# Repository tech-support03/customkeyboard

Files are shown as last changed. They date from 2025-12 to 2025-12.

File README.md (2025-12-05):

# customkeyboard

## A custom hotswapable keyboard with a 60% plus arrow keys layout

The purpose of this project was to learn about designing pcbs and how to make my own keyboard. I wanted to make something that was not a completely unique design but I wanted my own personal touch. It had to be small and portable, so I went with a 60% layout at first. However I really wanted arrow keys because they are very important to me in a keyboard layout, so I added them and it acutally led to better packaging overall. Another very important thing to me was hotswapability. I wanted the ability to change my switches if I wanted to. This led to its own set of challenges, but eventually it worked out pretty nicely. Additionally, I wanted a rotary encoder, so I put one in the top left corner. Finally, I wanted the microcontroller to be exposed because I think it looks pretty cool, so I made a cutout for it in the top right. Overall, this project was really fun to design!

### CAD
Full CAD




Top Plate


Base


PCB (Hotswap sockets!)


### PCB

Layout


Schematic


### BOM

| Item | Description | Link | Price | Quantity | Total |
|---|---|---|---|---|---|
| PCB | circuit board for all the components | https://jlcpcb.com | 20.70 | 1 | 22.64 |
| Raspberry Pi Pico | Microcontroller for keyboard | https://www.microcenter.com/product/661033/raspberry-pi-pico-microcontroller-development-board | 2.99  | 1 | 3.27 |
| Akko Cream Blue Switches | Tactile switches for keyboard, sold in packs of 45 | https://www.amazon.com/Akko-Cream-Blue-Tactile-Switches/dp/B0CL4FRWY8 | 25.98 | 1 | 28.41 |
| Womier Black keycaps | Keycaps for keyboard | https://www.amazon.com/Womier-Black-Pudding-Keycaps/dp/B0BN5F3B9S | 17.99 | 1 | 19.67 |
| Plate mount Stabilizers | Stabilizers for keyboard | https://www.amazon.com/Durock-Plate-Mount-Stabilizer/dp/B08T6CTRM8 | 9.99  | 1 | 10.92  |
| Kailh hotswap sockets | Sockets for hot-swappable switches | https://www.amazon.com/Kailh-Hot-Swap-Sockets/dp/B07ZHYJWLJ | 9.99  | 1 | 10.92 |
| 1N4148 Diodes | Diodes for the keyboard matrix | https://www.amazon.com/ALLECIN-1N4148-Schottky-Diodes/dp/B0BRF4SJGQ | 5.99  | 1 | 6.55 |
| EC11 Rotary Encoder with switch | Rotary encoder used for volume knob | https://keeb.io/products/rotary-encoder-ec11 | 1.99  | 1 | 2.18  |
| **Total:** | | | | | **104.56** |

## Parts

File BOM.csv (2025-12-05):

Item | Desciption | Link | Unit Price | Amount | Total
PCB | circuit board for all the components | https://cart.jlcpcb.com/quote?plateType=1 | 20.7 | 1 | 22.64
Raspberry Pi Pico | Microcontroller for keyboard | https://www.microcenter.com/product/661033/raspberry-pi-pico-microcontroller-development-board | 2.99 | 1 | 3.27
Akko Cream Blue Switches | Tactile switches for keyboard, sold in packs of 45 | https://www.amazon.com/gp/product/B0C3H7PR1Z?asc_campaign=&asc_source= | 12.99 | 2 | 28.41
Womier Black keycaps | Keycaps for the keyboard | https://www.amazon.com/Keycaps-Profile-Percent-Mechanical-Keyboard/dp/B0DHR6D697 | 17.99 | 1 | 19.67
Plate mount Stablilizers | Stablizers, an important part of the keyboard so the bigger keys stay level and you are able to press them evenly from any part of the keyboard | https://www.amazon.com/DUROCK-Stabilizer-Innovative-Pre-clipped-Stabilizers/dp/B0CTHT34MJ | 9.99 | 1 | 10.92
Kailh hotswap sockets | hotswap sockets which will be soldered to board | https://www.amazon.com/VEGNRSOT-Hot-swap-Mechanical-Keyboard-Accessories/dp/B0CZ79H1D9 | 9.99 | 1 | 10.92
1N4148 Diodes | diodes for keyboard matrix | https://www.amazon.com/ALLECIN-1N4148-Schottky-Switching-Package/dp/B0CKRMK45V?sp_csd=d2lkZ2V0TmFtZT1zcF9hdGY | 5.99 | 1 | 6.55
EC11 Rotary Encoder with switch | the rotary encoder dial | https://keeb.io/products/rotary-encoder-ec11 | 1.99 | 1 | 2.18
 |  |  |  | Total: | 104.56

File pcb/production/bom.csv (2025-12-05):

Designator | Footprint | Quantity | Value | LCSC Part #
A1 | RaspberryPi_Pico_Common_Unspecified | 1 | RaspberryPi_Pico
D1, D10, D11, D12, D13, D14, D15, D16, D17, D18, D19, D2, D20, D21, D22, D23, D24, D25, D26, D27, D28, D29, D3, D30, D31, D32, D33, D34, D35, D36, D37, D38, D39, D4, D40, D41, D42, D43, D44, D45, D46, D47, D48, D49, D5, D50, D51, D52, D53, D54, D55, D56, D57, D58, D59, D6, D60, D61, D62, D63, D64, D65, D7, D8, D9 | D_DO-35_SOD27_P7.62mm_Horizontal | 65 | 1N4148
SW1, SW10, SW11, SW12, SW13, SW16, SW17, SW18, SW19, SW2, SW20, SW21, SW22, SW23, SW24, SW25, SW26, SW27, SW3, SW30, SW31, SW32, SW33, SW34, SW35, SW36, SW37, SW38, SW39, SW4, SW40, SW43, SW44, SW45, SW46, SW47, SW48, SW49, SW5, SW50, SW51, SW52, SW6, SW62, SW63, SW64, SW65, SW7, SW8, SW9 | SW_Hotswap_Kailh_MX_1.00u | 50 | SW_Push_45deg
SW14 | SW_Hotswap_Kailh_MX_2.00u | 1 | SW_Push_45deg
SW15, SW28 | SW_Hotswap_Kailh_MX_1.50u | 2 | SW_Push_45deg
SW29 | SW_Hotswap_Kailh_MX_1.75u | 1 | SW_Push_45deg
SW41, SW42 | SW_Hotswap_Kailh_MX_2.25u | 2 | SW_Push_45deg
SW53 | SW_Hotswap_Kailh_MX_2.75u | 1 | SW_Push_45deg
SW54, SW55, SW56, SW58, SW59, SW60, SW61 | SW_Hotswap_Kailh_MX_1.25u | 7 | SW_Push_45deg
SW57 | SW_Hotswap_Kailh_MX_6.25u | 1 | SW_Push_45deg
SW77 | RotaryEncoder_Alps_EC11E-Switch_Vertical_H20mm | 1 | RotaryEncoder_Switch

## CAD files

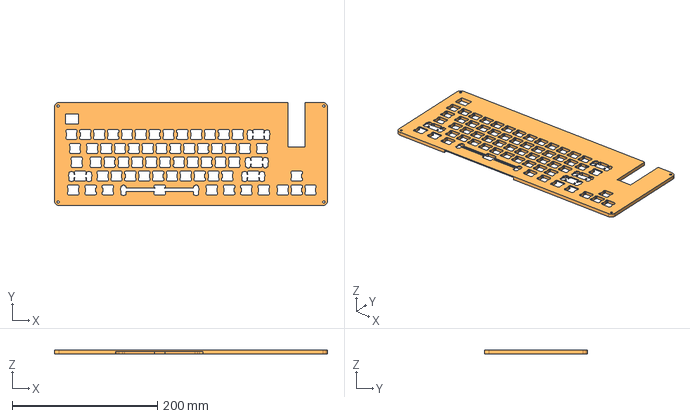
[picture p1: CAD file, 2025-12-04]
cad/top_plate.step
375.5 x 142.0 x 5.00 mm

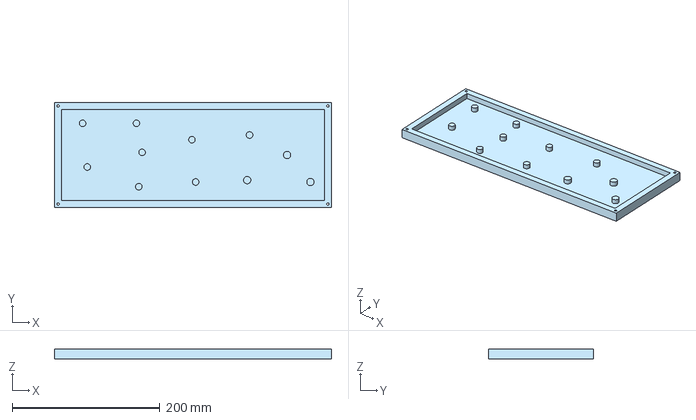
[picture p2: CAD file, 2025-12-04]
cad/base.step
375.5 x 143.0 x 13.0 mm

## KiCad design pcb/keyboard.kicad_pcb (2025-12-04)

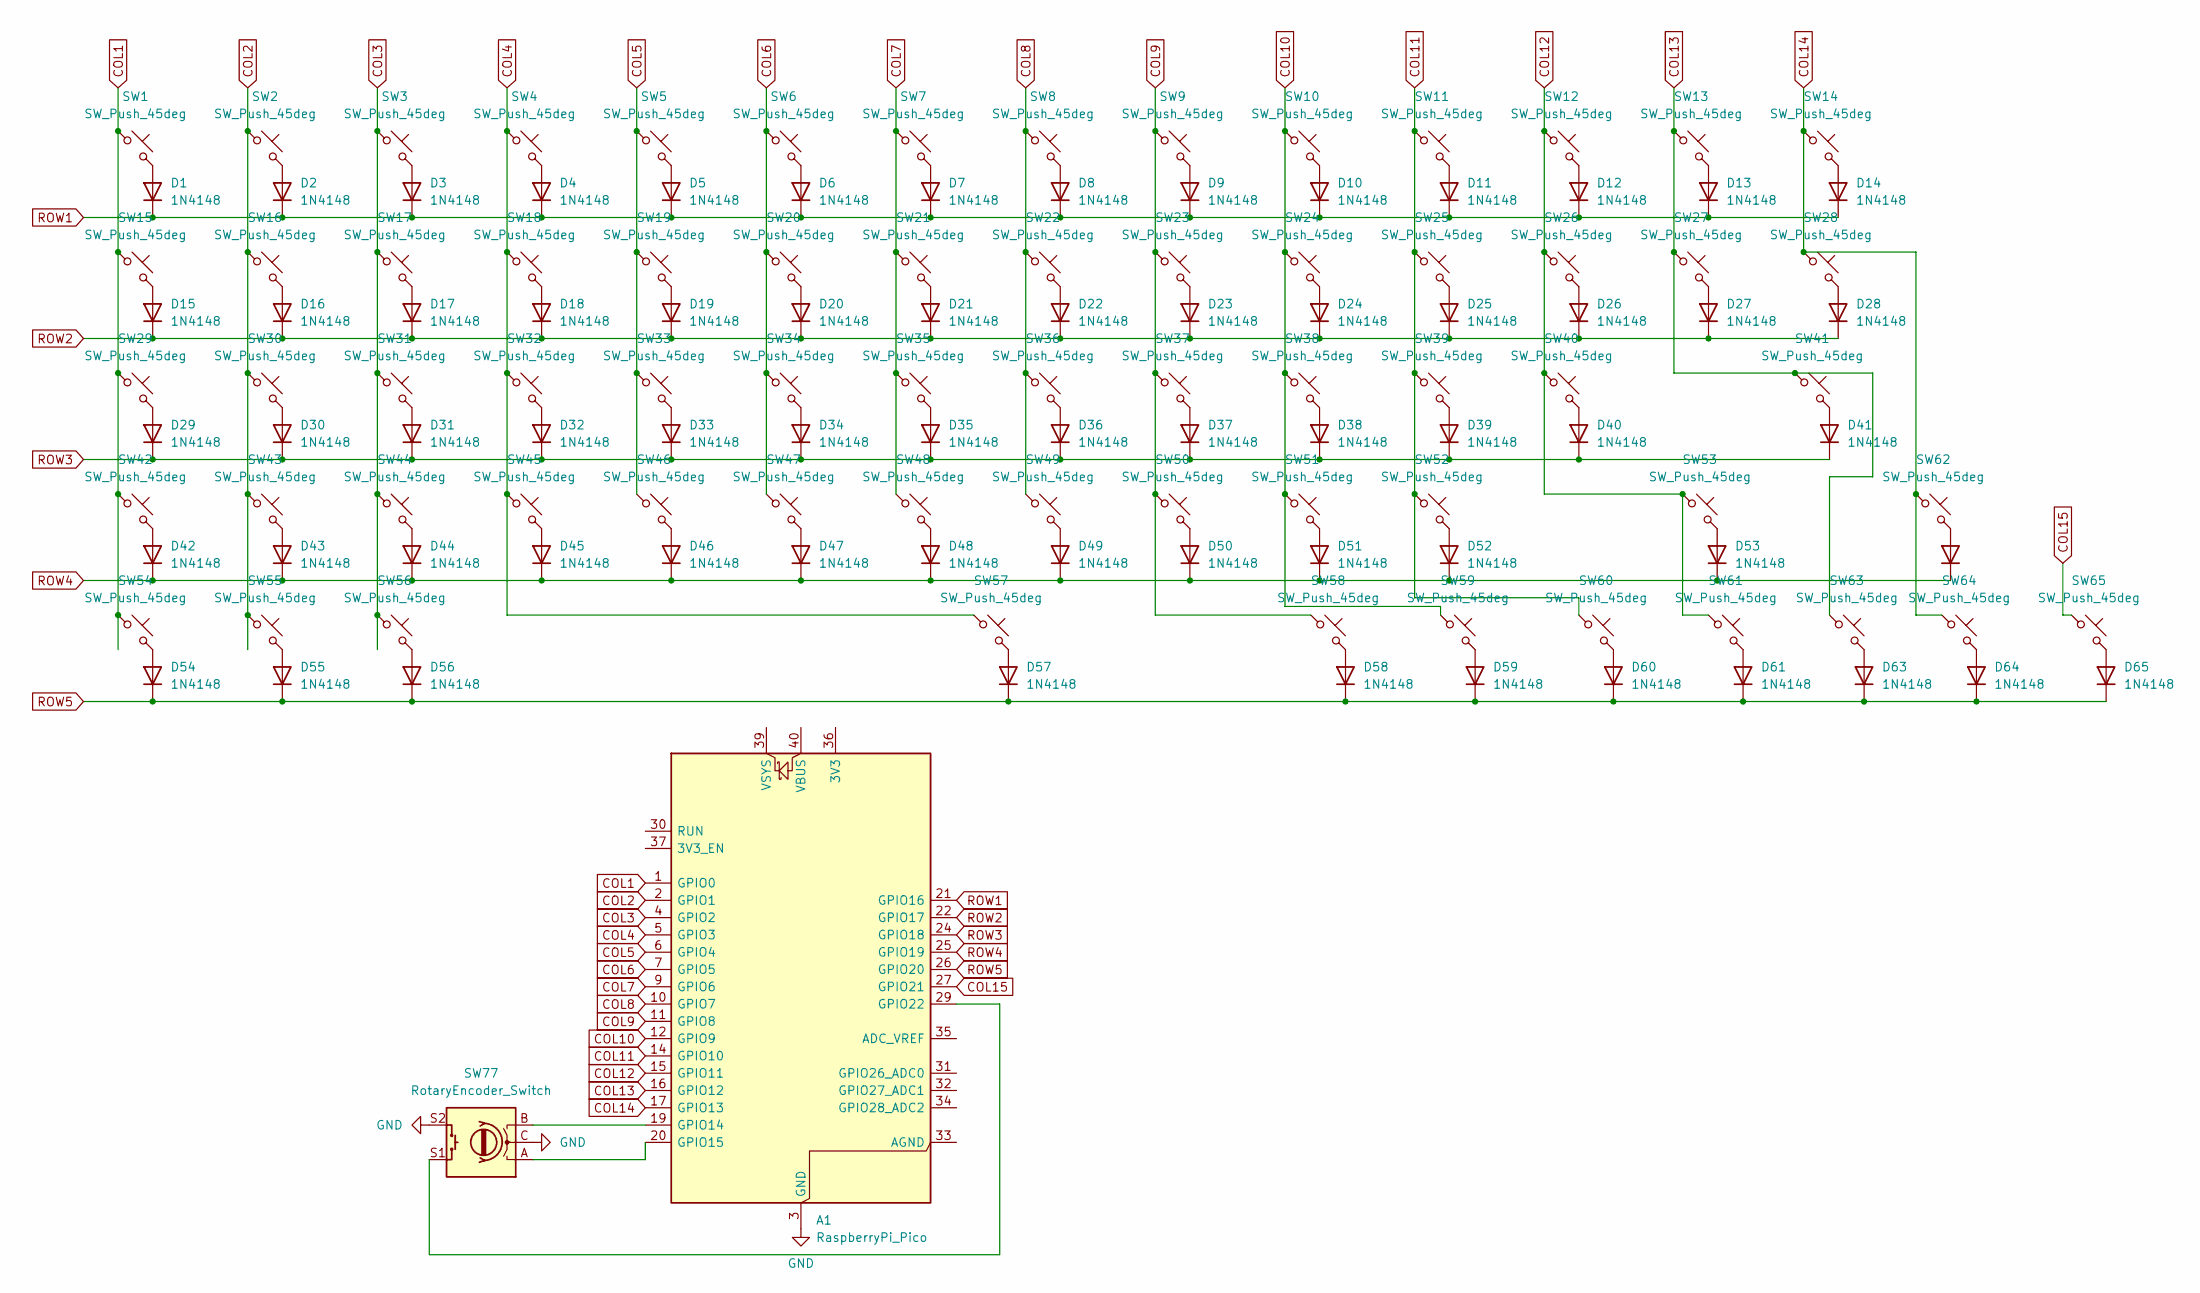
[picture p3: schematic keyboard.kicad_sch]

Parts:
A1: RaspberryPi_Pico; RaspberryPi_Pico_Common_Unspecified
D1, D2, D3, D4, D5, D6, D7, D8, D9, D10, D11, D12, D13, D14, D15, D16, D17, D18, D19, D20, D21, D22, D23, D24, D25, D26, D27, D28, D29, D30, D31, D32, D33, D34, D35, D36, D37, D38, D39, D40, D41, D42, D43, D44, D45, D46, D47, D48, D49, D50, D51, D52, D53, D54, D55, D56, D57, D58, D59, D60, D61, D62, D63, D64, D65: 1N4148; D_DO-35_SOD27_P7.62mm_Horizontal
SW1, SW2, SW3, SW4, SW5, SW6, SW7, SW8, SW9, SW10, SW11, SW12, SW13, SW16, SW17, SW18, SW19, SW20, SW21, SW22, SW23, SW24, SW25, SW26, SW27, SW30, SW31, SW32, SW33, SW34, SW35, SW36, SW37, SW38, SW39, SW40, SW43, SW44, SW45, SW46, SW47, SW48, SW49, SW50, SW51, SW52, SW62, SW63, SW64, SW65: SW_Push_45deg; SW_Hotswap_Kailh_MX_1.00u
SW14: SW_Push_45deg; SW_Hotswap_Kailh_MX_2.00u
SW15, SW28: SW_Push_45deg; SW_Hotswap_Kailh_MX_1.50u
SW29: SW_Push_45deg; SW_Hotswap_Kailh_MX_1.75u
SW41, SW42: SW_Push_45deg; SW_Hotswap_Kailh_MX_2.25u
SW53: SW_Push_45deg; SW_Hotswap_Kailh_MX_2.75u
SW54, SW55, SW56, SW58, SW59, SW60, SW61: SW_Push_45deg; SW_Hotswap_Kailh_MX_1.25u
SW57: SW_Push_45deg; SW_Hotswap_Kailh_MX_6.25u
SW77: RotaryEncoder_Switch; RotaryEncoder_Alps_EC11E-Switch_Vertical_H20mm

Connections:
COL1: A1.1 (GPIO0), SW1.1, SW15.1, SW29.1, SW42.1, SW54.1
COL2: A1.2 (GPIO1), SW2.1, SW16.1, SW30.1, SW43.1, SW55.1
COL3: A1.4 (GPIO2), SW3.1, SW17.1, SW31.1, SW44.1, SW56.1
COL4: A1.5 (GPIO3), SW4.1, SW18.1, SW32.1, SW45.1, SW57.1
COL5: A1.6 (GPIO4), SW5.1, SW19.1, SW33.1, SW46.1
COL6: A1.7 (GPIO5), SW6.1, SW20.1, SW34.1, SW47.1
COL7: A1.9 (GPIO6), SW7.1, SW21.1, SW35.1, SW48.1
COL8: A1.10 (GPIO7), SW8.1, SW22.1, SW36.1, SW49.1
COL9: A1.11 (GPIO8), SW9.1, SW23.1, SW37.1, SW50.1, SW58.1
COL10: A1.12 (GPIO9), SW10.1, SW24.1, SW38.1, SW51.1, SW59.1
COL11: A1.14 (GPIO10), SW11.1, SW25.1, SW39.1, SW52.1, SW60.1
COL12: A1.15 (GPIO11), SW12.1, SW26.1, SW40.1, SW53.1, SW61.1
COL13: A1.16 (GPIO12), SW13.1, SW27.1, SW41.1, SW63.1
COL14: A1.17 (GPIO13), SW14.1, SW28.1, SW62.1, SW64.1
COL15: A1.27 (GPIO21), SW65.1
GND: A1.3 (GND), A1.8 (GND), A1.13 (GND), A1.18 (GND), A1.23 (GND), A1.28 (GND), A1.38 (GND), SW77.C, SW77.S2
unnamed: A1.19 (GPIO14), SW77.B
unnamed: A1.20 (GPIO15), SW77.A
unnamed: A1.29 (GPIO22), SW77.S1
unnamed: D1.2 (A), SW1.2
unnamed: D2.2 (A), SW2.2
unnamed: D3.2 (A), SW3.2
unnamed: D4.2 (A), SW4.2
unnamed: D5.2 (A), SW5.2
unnamed: D6.2 (A), SW6.2
unnamed: D7.2 (A), SW7.2
unnamed: D8.2 (A), SW8.2
unnamed: D9.2 (A), SW9.2
unnamed: D10.2 (A), SW10.2
unnamed: D11.2 (A), SW11.2
unnamed: D12.2 (A), SW12.2
unnamed: D13.2 (A), SW13.2
unnamed: D14.2 (A), SW14.2
unnamed: D15.2 (A), SW15.2
unnamed: D16.2 (A), SW16.2
unnamed: D17.2 (A), SW17.2
unnamed: D18.2 (A), SW18.2
unnamed: D19.2 (A), SW19.2
unnamed: D20.2 (A), SW20.2
unnamed: D21.2 (A), SW21.2
unnamed: D22.2 (A), SW22.2
unnamed: D23.2 (A), SW23.2
unnamed: D24.2 (A), SW24.2
unnamed: D25.2 (A), SW25.2
unnamed: D26.2 (A), SW26.2
unnamed: D27.2 (A), SW27.2
unnamed: D28.2 (A), SW28.2
unnamed: D29.2 (A), SW29.2
unnamed: D30.2 (A), SW30.2
unnamed: D31.2 (A), SW31.2
unnamed: D32.2 (A), SW32.2
unnamed: D33.2 (A), SW33.2
unnamed: D34.2 (A), SW34.2
unnamed: D35.2 (A), SW35.2
unnamed: D36.2 (A), SW36.2
unnamed: D37.2 (A), SW37.2
unnamed: D38.2 (A), SW38.2
unnamed: D39.2 (A), SW39.2
unnamed: D40.2 (A), SW40.2
unnamed: D41.2 (A), SW41.2
unnamed: D42.2 (A), SW42.2
unnamed: D43.2 (A), SW43.2
unnamed: D44.2 (A), SW44.2
unnamed: D45.2 (A), SW45.2
unnamed: D46.2 (A), SW46.2
unnamed: D47.2 (A), SW47.2
unnamed: D48.2 (A), SW48.2
unnamed: D49.2 (A), SW49.2
unnamed: D50.2 (A), SW50.2
unnamed: D51.2 (A), SW51.2
unnamed: D52.2 (A), SW52.2
unnamed: D53.2 (A), SW53.2
unnamed: D54.2 (A), SW54.2
unnamed: D55.2 (A), SW55.2
unnamed: D56.2 (A), SW56.2
unnamed: D57.2 (A), SW57.2
unnamed: D58.2 (A), SW58.2
unnamed: D59.2 (A), SW59.2
unnamed: D60.2 (A), SW60.2
unnamed: D61.2 (A), SW61.2
unnamed: D62.2 (A), SW62.2
unnamed: D63.2 (A), SW63.2
unnamed: D64.2 (A), SW64.2
unnamed: D65.2 (A), SW65.2
ROW1: A1.21 (GPIO16), D1.1 (K), D2.1 (K), D3.1 (K), D4.1 (K), D5.1 (K), D6.1 (K), D7.1 (K), D8.1 (K), D9.1 (K), D10.1 (K), D11.1 (K), D12.1 (K), D13.1 (K), D14.1 (K)
ROW2: A1.22 (GPIO17), D15.1 (K), D16.1 (K), D17.1 (K), D18.1 (K), D19.1 (K), D20.1 (K), D21.1 (K), D22.1 (K), D23.1 (K), D24.1 (K), D25.1 (K), D26.1 (K), D27.1 (K), D28.1 (K)
ROW3: A1.24 (GPIO18), D29.1 (K), D30.1 (K), D31.1 (K), D32.1 (K), D33.1 (K), D34.1 (K), D35.1 (K), D36.1 (K), D37.1 (K), D38.1 (K), D39.1 (K), D40.1 (K), D41.1 (K)
ROW4: A1.25 (GPIO19), D42.1 (K), D43.1 (K), D44.1 (K), D45.1 (K), D46.1 (K), D47.1 (K), D48.1 (K), D49.1 (K), D50.1 (K), D51.1 (K), D52.1 (K), D53.1 (K), D62.1 (K)
ROW5: A1.26 (GPIO20), D54.1 (K), D55.1 (K), D56.1 (K), D57.1 (K), D58.1 (K), D59.1 (K), D60.1 (K), D61.1 (K), D63.1 (K), D64.1 (K), D65.1 (K)

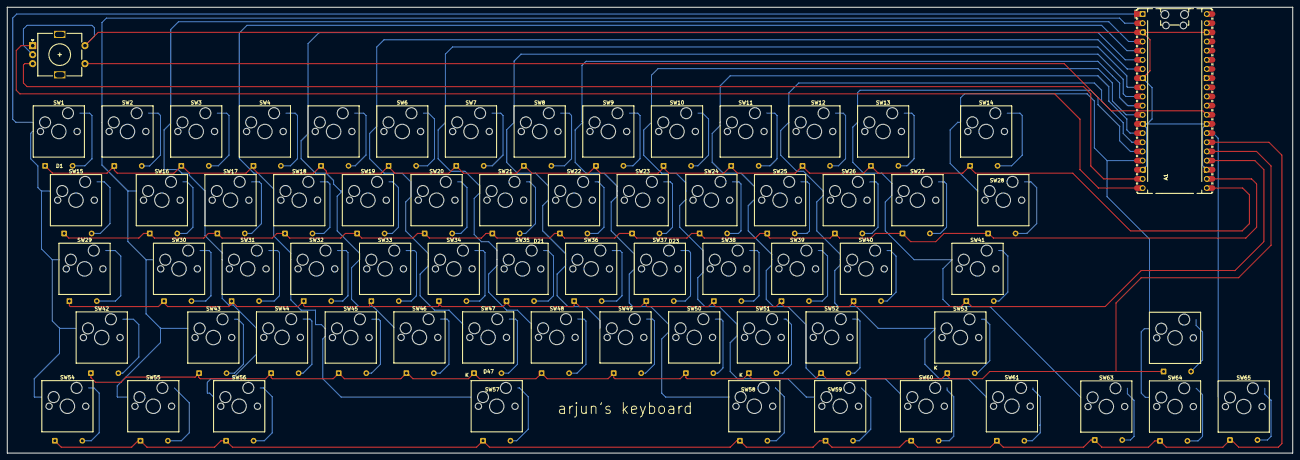
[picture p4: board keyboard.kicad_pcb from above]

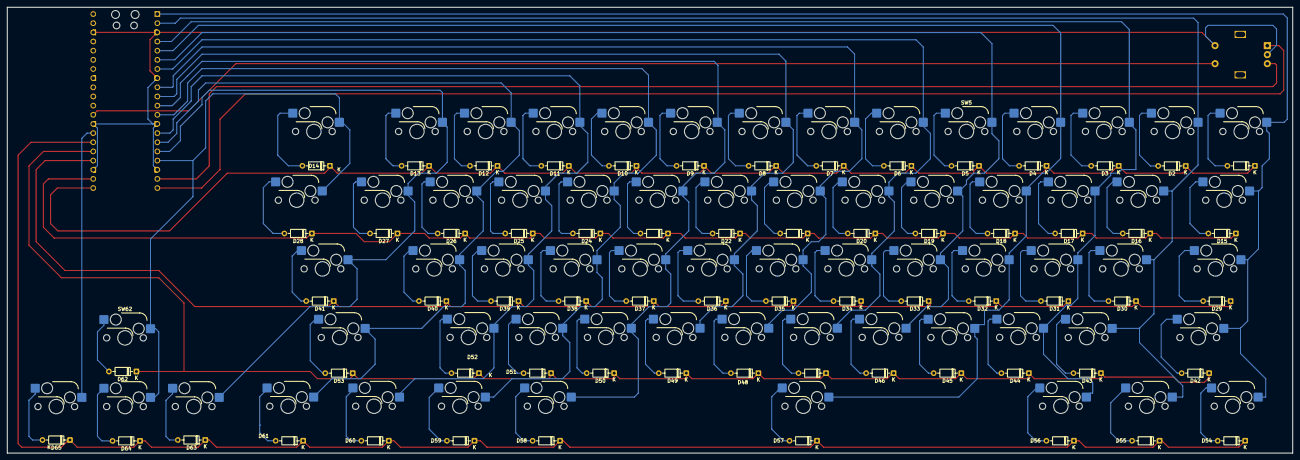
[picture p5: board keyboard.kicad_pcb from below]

Board: 2 copper layers, 356.5 x 123.6 mm, 132 parts (65 on the bottom side), 89 nets.

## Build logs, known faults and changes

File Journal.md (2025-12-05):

# Journal

## Total hours spent: 16 Hours

### Dates and Time spent that day:
- 12/1: 4 Hours
- 12/2: 3.5 Hours
- 12/3: 5.5 Hours
- 12/4: 3 Hours

Full CAD


PCB Layout


PCB Schematic


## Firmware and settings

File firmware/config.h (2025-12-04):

#pragma once

#define VENDOR_ID       0xFEED
#define PRODUCT_ID      0x6060
#define DEVICE_VER      0x0001
#define MANUFACTURER    arjunkhedkar
#define PRODUCT         arjun's_keyboard

// Matrix configuration
#define MATRIX_ROWS 5
#define MATRIX_COLS 15

// Pin configuration for RP2040
#define MATRIX_ROW_PINS { GP16, GP17, GP18, GP19, GP20 }
#define MATRIX_COL_PINS { GP0, GP1, GP2, GP3, GP4, GP5, GP6, GP7, GP8, GP9, GP10, GP11, GP12, GP13, GP21 }

#define DIODE_DIRECTION COL2ROW

// Rotary encoder configuration
#define ENCODERS_PAD_A { GP14 }
#define ENCODERS_PAD_B { GP15 }
#define ENCODER_RESOLUTION 4

// Encoder button (switch on encoder)
#define ENCODER_BUTTON_PIN GP22

// Debounce
#define DEBOUNCE 5

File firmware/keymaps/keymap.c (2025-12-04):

#include QMK_KEYBOARD_H

const uint16_t PROGMEM keymaps[][MATRIX_ROWS][MATRIX_COLS] = {
    [0] = LAYOUT_60_ansi_arrow(
        KC_ESC,  KC_1,    KC_2,    KC_3,    KC_4,    KC_5,    KC_6,    KC_7,    KC_8,    KC_9,    KC_0,    KC_MINS, KC_EQL,  KC_BSPC,
        KC_TAB,  KC_Q,    KC_W,    KC_E,    KC_R,    KC_T,    KC_Y,    KC_U,    KC_I,    KC_O,    KC_P,    KC_LBRC, KC_RBRC, KC_BSLS,
        KC_CAPS, KC_A,    KC_S,    KC_D,    KC_F,    KC_G,    KC_H,    KC_J,    KC_K,    KC_L,    KC_SCLN, KC_QUOT,          KC_ENT,
        KC_LSFT, KC_Z,    KC_X,    KC_C,    KC_V,    KC_B,    KC_N,    KC_M,    KC_COMM, KC_DOT,  KC_SLSH, KC_RSFT, KC_UP,   MO(1),
        KC_LCTL, KC_LGUI, KC_LALT,                   KC_SPC,                             KC_RALT, KC_LEFT, KC_DOWN, KC_RGHT
    ),
    [1] = LAYOUT_60_ansi_arrow(
        KC_GRV,  KC_F1,   KC_F2,   KC_F3,   KC_F4,   KC_F5,   KC_F6,   KC_F7,   KC_F8,   KC_F9,   KC_F10,  KC_F11,  KC_F12,  KC_DEL,
        _______, _______, _______, _______, _______, _______, _______, _______, _______, _______, _______, _______, _______, _______,
        _______, _______, _______, _______, _______, _______, _______, _______, _______, _______, _______, _______,          _______,
        _______, _______, _______, _______, _______, _______, _______, _______, _______, _______, _______, _______, KC_PGUP, _______,
        _______, _______, _______,                   _______,                            _______, KC_HOME, KC_PGDN, KC_END
    )
};

// Rotary encoder handling
bool encoder_update_user(uint8_t index, bool clockwise) {
    if (index == 0) {
        if (clockwise) {
            tap_code(KC_VOLU);
        } else {
            tap_code(KC_VOLD);
        }
    }
    return false;
}

// Handle encoder button press
void matrix_scan_user(void) {
    static bool encoder_button_pressed = false;
    bool current_state = !readPin(ENCODER_BUTTON_PIN);
    
    if (current_state && !encoder_button_pressed) {
        tap_code(KC_MUTE);
        encoder_button_pressed = true;
    } else if (!current_state && encoder_button_pressed) {
        encoder_button_pressed = false;
    }
}

void keyboard_post_init_user(void) {
    setPinInputHigh(ENCODER_BUTTON_PIN);
}

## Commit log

2025-12-04 Add base and top plate files
    [base.step, top_plate.step]
2025-12-04 add full keyboard CAD
    the STEP file was too big for github so had to compress into a zip
2025-12-04 move file?
    [keyboard.kicad_pcb]
2025-12-04 Add all PCB files
    [keyboard.kicad_pcb, keyboard.kicad_sch]
2025-12-04 Add keymap and rotary encoder functionality
    Define keymaps for a 60% keyboard layout and implement rotary encoder handling.
2025-12-04 updated pcb files
    [keyboard.kicad_pcb, keyboard.kicad_sch]
2025-12-05 add journal
    [BOM.csv, bom.csv, designators.csv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]
2025-12-05 Enhance README with project details and images
    Expanded project description and added CAD, PCB, and BOM sections with images and details.
2025-12-05 Add images to CAD section in README
    Added additional images to the CAD section of the README.
2025-12-05 Revise BOM prices and total calculations
    Updated prices and totals for BOM items.
